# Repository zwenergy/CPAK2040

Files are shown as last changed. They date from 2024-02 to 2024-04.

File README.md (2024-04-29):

# CPAK2040
An RP2040-based controller pak for the N64.

## Overview
The main idea of CPAK2040 is to a have a simple, cheap and easily DIY-able controller pak alternative for the N64 which is non-volatile (meaning not relying on a battery to keep the controller pak data like the original based on SRAM). 
For this, a Raspberry Pi Pico board is used, as it is widely available, cheap and easy to solder even for beginners.

A regular Raspberry Pi Pico board has a 2 MB Flash, whereas a single N64 controller pak has a capacity of 32 kB.
The software running on the Pico to emulate the controller pak only takes up a fraction of the available Flash memory, hence quite many "virtual controller paks" can be stored in the Pico's Flash.
By default, the CPAK2040 holds 10 "virtual controller paks", as a more efficient navigating method needs to implemented to better use a larger number of controller paks.

**DO NOT CONNECT VIA USB WHEN PLUGGED IN A CONTROLLER!**

## BOM
Well, the BOM is short.
You need the **PCB** and a **Raspberry Pi Pico board**. 
**Don't use a Pi Pico W board**, use a regular one.

## PCB
The Gerber files to create the PCB can be found in the "gerber" folder.
You need to order the PCB with **1.2 mm thickness**, **ENIG or hard gold** and **bevelled edges** at the connector.
Using regular HASL is not recommended, as the PCB contacts quickly wear down, while solder may also rub onto the controller's connection pins.

## Setting up the Pi Pico
Hold down the BOOTSEL button, connect the Pi Pico via USB to your computer and drag'n'drop the .UF2 from the latest release onto the Pi Pico device.

## Using the CPAK2040
If you're using the CPAK2040 without the 3D printed case, make sure that you orientate the PCB correctly.
It's noted on the PCB, which side should face the front of the controller ("controller cable side") and which to the back of the controller ("Z-trigger side").

Initially, all virtual controller paks will be "corrupted", as they are not formatted as a controller pak data.
Start a game using a controller pak and hold START during the startup, this will bring up the controller pak manager.
Here, you can typically "repair" aka format the current virtual controller pak.

### Storing behaviour
The current controller pak's content is hold in the RP2040's SRAM.
When a write the controller pak happens, the updated contents are stored into the Flash.
In order to avoid unneccassary writes to the Flash, the Flash content is not directly updated, but a small timeout of some seconds is introduced, such that multiple writes can be combined into a single Flash rewrite.
This is signaled using the Pico's LED.
When then LED is on, this means that there is fresh data in the controller pak which is not written back to the Flash yet.
**Do not unplug the controller pak, while the LED is on, or otherwise you risk losing the latest controller pak data or data corruption.**

This delayed storing behaviour is done to reduce the number of Flash rewrites.
The Flash has a limited number of writes of ca. 100,000 before it wears out.
**This also means, that each "virtual controller pak" on the CPAK2040 has a lifetime of around 100,000 writes.**
Realistically, this should be enough forever for most people I guess.
If you save each day 10 times to the controller pak, you can do that for 27 years straight before you're getting close the 100,000 writes.

### Changing Virtual Controller Pak
To change the current virtual controller pak (VCP), shortly the BOOTSEL button down (<1 second).
The CPAK2040 will jump to the next VCP, indicating the current index by flashing the LED.
After the last VCP, the index will jump back to the first.
The current VCP index is stored into the Flash after 2s not changing it, so also after unplugging the CPAK2040 it will remember the last VCP used.

Note that many games will not reload the controller pak content, unless they sense that the controller pak is physically removed and plugged back in again.

The simple "hold button to increase VCP index" is not ideal, especially with a larger number of VCPs.
I am planning on adding a better navigating scheme.

### Backup Controller Pak Data
When plugging in the CPAK2040 via USB to a computer, the BOOTSEL button long (>2 seconds) and let go (**AFTER** plugging in via USB).
This enables USB read mode, which registers the CPAK2040 as a mass storage device and all the controller paks can be copied off the device (this is implemented using TinyUSB).
There is currently no way to manually exit the USB mode again, so the CPAK2040 needs to be unplugged before used again normally.

### Writing Controller Pak Data
This is currently still in **experimental mode**.

**ALWAYS MAKE A BACKUP OF YOUR SAVE GAMES!**

To enter USB write mode, hold the BOOTSEL button long (>2 seconds), let go shortly, then again hold it long (**AFTER** plugging in via USB).
This enables USB write mode, which registers the CPAK2040 as a mass storage device.
In this mode, only the current chosen VCP is visible and named "MEMPAK.MPK".
**IMPORTANT: Wait 5 seconds after mounting the USB drive before continuing.**
In order to replace this VCP, rename the memory pak file to be written to the CPAK2040 also to "MEMPAK.MPK" and copy it to the CPAK2040 drive (so it replaces the file on the drive).
After writing, the CPAK2040 should automatically disconnect and restart, showing the current chosen VCP via the blinking LED.

## Shell
A first version of a 3D printable shell can be found in the STL folder.

## Disclaimer
**Use the files and/or schematics to build your own board at your own risk**.
This board works fine for me, but it's a simple hobby project, so there is no liability for errors in the schematics and/or board files.
**Use at your own risk**.

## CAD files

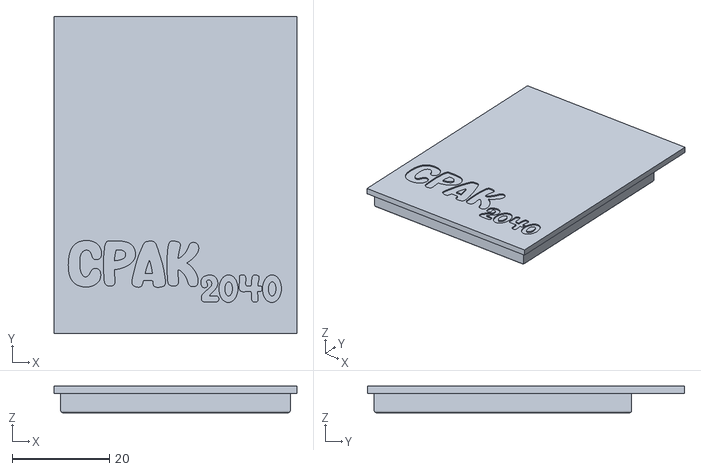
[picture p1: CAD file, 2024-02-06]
stl/front.stl
50.0 x 65.2 x 5.50

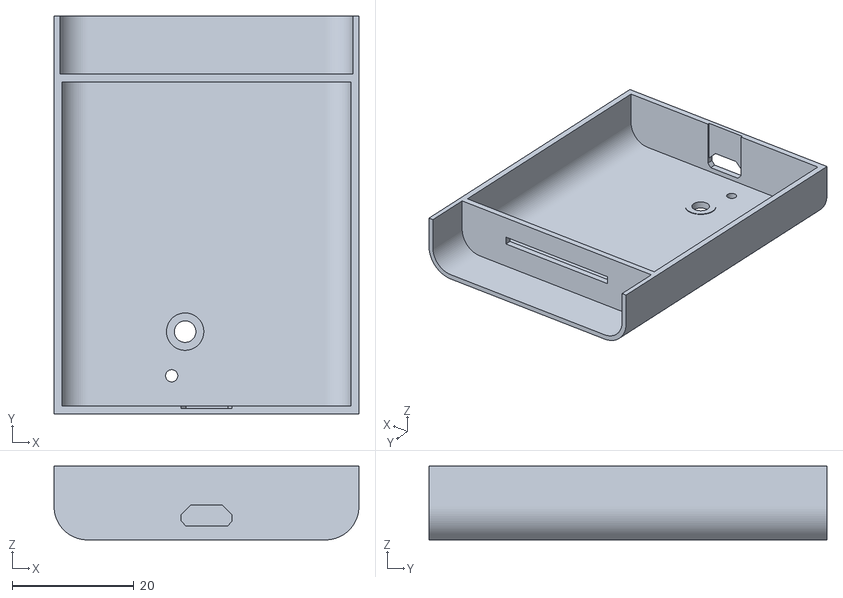
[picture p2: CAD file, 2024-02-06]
stl/back.stl
50.0 x 65.2 x 12.1

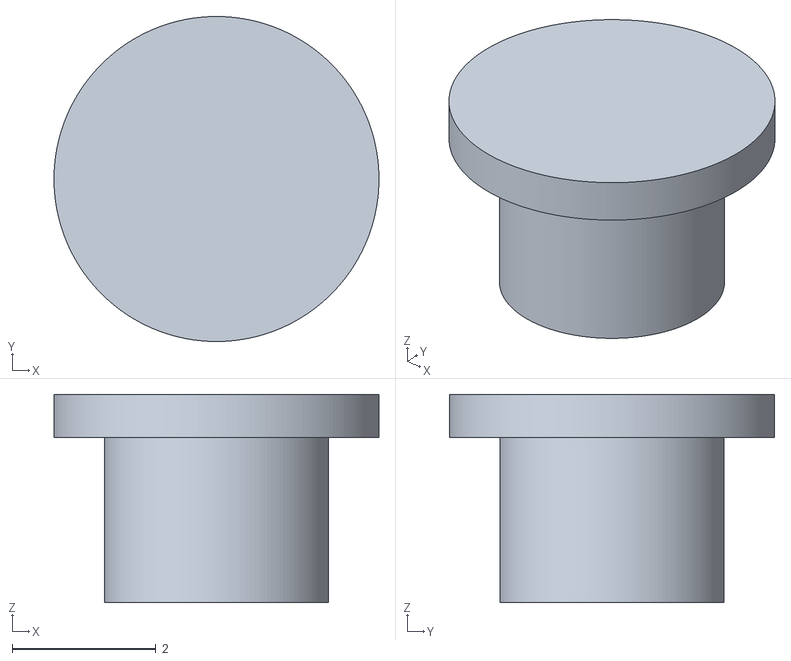
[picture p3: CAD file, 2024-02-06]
stl/button.stl
4.53 x 4.53 x 2.90

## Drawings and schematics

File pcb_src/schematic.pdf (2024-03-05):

A | A

1

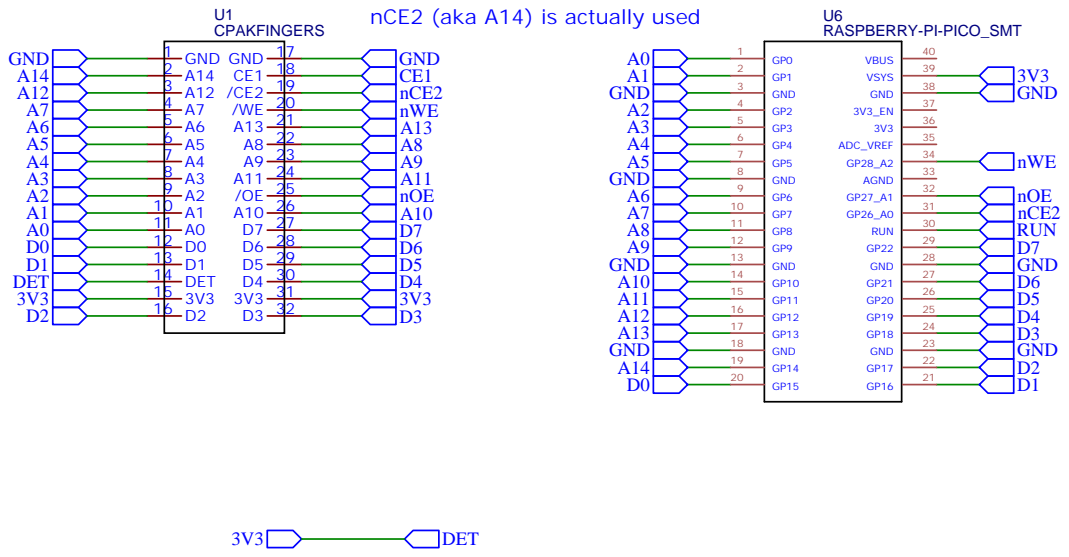
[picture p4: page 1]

nCE2 (aka A14) is actually used

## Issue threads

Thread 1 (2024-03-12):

Could vibration function be added?

natlus2, 2024-03-12:
the possibility of adding vibration, using the rumble of a mobile phone for example.

I don't know if it would be possible to run memory pak and rumble pak at the same time, if it were not possible, you could alternate between modes.

zwenergy, 2024-03-13:
It's difficult with the current simplicity of just using a single Pico, because there is not a single GPIO left to use to control a rumble motor. If I do a new version, which is not based on the Pico, but an own design around the RP2040, I could add this.

Closed 2024-03-13.

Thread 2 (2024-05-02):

Can not comiple !?

kirk33, 2024-05-02:
I try to compile, but it can not. I miss something ?

In file included from C:\PicoSDK\pico-sdk\lib\tinyusb\src/tusb.h:73,
                        from Z:\cpak\code\usb_descriptors.c:26:
C:\PicoSDK\pico-sdk\lib\tinyusb\src/device/usbd.h:247:58: error: 'MSC_SUBCLASS_SCSI' undeclared here (not in a function)

  247 |   9, TUSB_DESC_INTERFACE, _itfnum, 0, 2, TUSB_CLASS_MSC, MSC_SUBCLASS_SCSI, MSC_PROTOCOL_BOT, _stridx,\
      |                                                          ^~~~~~~~~~~~~~~~~
Z:\cpak\code\usb_descriptors.c:100:3: note: in expansion of macro 'TUD_MSC_DESCRIPTOR'
  100 |   TUD_MSC_DESCRIPTOR(ITF_NUM_MSC, 3 , EPNUM_MSC_OUT, EPNUM_MSC_IN, 64),
      |   ^~~~~~~~~~~~~~~~~~
C:\PicoSDK\pico-sdk\lib\tinyusb\src/device/usbd.h:247:77: error: 'MSC_PROTOCOL_BOT' undeclared here (not in a function);
 did you mean 'HID_PROTOCOL_BOOT'?
  247 |   9, TUSB_DESC_INTERFACE, _itfnum, 0, 2, TUSB_CLASS_MSC, MSC_SUBCLASS_SCSI, MSC_PROTOCOL_BOT, _stridx,\
      |                                                                             ^~~~~~~~~~~~~~~~
Z:\cpak\code\usb_descriptors.c:100:3: note: in expansion of macro 'TUD_MSC_DESCRIPTOR'
  100 |   TUD_MSC_DESCRIPTOR(ITF_NUM_MSC, 3 , EPNUM_MSC_OUT, EPNUM_MSC_IN, 64),

Closed 2024-05-03.

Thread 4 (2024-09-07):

[HELP] 30 mempacks

davidxgames, 2024-09-07:
"I couldn't increase it to more than 15 mempacks. Is it possible to do so, or would that be the limit? I would like to have about 30. Could you help me?"

zwenergy, 2024-09-08:
How exactly does your issue look like? For the USB functionality you'd need to adapt the FAT12 system, but the "pure" memory pack functionality should be working I think despite.

davidxgames, 2024-09-08:
> How exactly does your issue look like? For the USB functionality you'd need to adapt the FAT12 system, but the "pure" memory pack functionality should be working I think despite.

It works perfectly for me, except I want to add more mempacks but I can only do it up to 15:

`'M', 'E', 'M', 'P', 'A', 'K', '1', '5', 'M', 'P', 'K', 0x20, 0x00, 0xC6, 0x52, 0x6D,
                0x65, 0x43, 0x65, 0x43, 0x00, 0x00, 0x88, 0x6D, 0x65, 0x43, 0x42, 0x00,
                0x00, 0x80, 0x00, 0x00,

#define NRMEMPAKS 15`

But I can't add more, I even added a function so that if you quickly press the button twice it returns to the previous mempack.

I also added a second rp2040 to display the current mempack on a screen.

Could you tell me how to add more mempacks?

I don't speak English, I use Google Translate, so sorry.

zwenergy, 2024-09-09:
> `'M', 'E', 'M', 'P', 'A', 'K', '1', '5', 'M', 'P', 'K', 0x20, 0x00, 0xC6, 0x52, 0x6D,
0x65, 0x43, 0x65, 0x43, 0x00, 0x00, 0x88, 0x6D, 0x65, 0x43, 0x42, 0x00,
0x00, 0x80, 0x00, 0x00,

You also would have to adjust the FAT12 table, not just the root directory. Maybe also parts of the boot sector, I'm not sure about the sizes I put there right now. If you don't speak English, it would be probably the best if you would search for something like "FAT12 file system" in your native language to find an overview, how it is structured.

> edit: I understand, you're telling me that the 30 mempacks work on the console but I won't be able to see more than 15 when I connect to the PC?

Yes, I think if you only change the number of packs in main.c, it should still work on the console, but the regular USB storage view would be messed up.

davidxgames, 2024-09-11:
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

Hello, thanks for responding. I already tried modifying the FAT12 system, but I can't get it to work. I managed to compile with the 30 mempacks without errors, but when I connect it to the PC, it says the drive needs to be formatted. The thing is, I don't know how to program; the little I know, I've learned by modifying existing code. Hopefully, one day you'll have time to add more mempacks. With 30, I think it would be enough to have a definitive N64 controller pack.

I will send you a video via the social network X so you can see how I implemented the display to indicate the current mempack.

zwenergy, 2024-09-11:
Yeah, unfortunately it's not as simple as just adding more lines to the root directory part. The entries of the root directory part also point to the first sector of the file in the FAT table, so you would need to add sectors to the FAT and then set the right sector address in the newly added root directory entry.

Closed 2024-09-11.

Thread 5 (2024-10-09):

RumblePak only

davidxgames, 2024-10-09:
Hi, I saw that you commented on another issue (link: https://github.com/zwenergy/CPAK2040/issues/1) that adding rumble was possible, but not with the Pi Pico. Do you have any plans to emulate just the Rumble Pack using a Pi Pico?
Thank you in advance.

davidxgames, 2024-10-24:
I managed to emulate the rumble pak.

Closed 2024-10-24.

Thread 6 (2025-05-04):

extract the .uf2

FranTerrassa, 2025-05-04:
Hi, I've been trying to extract the .uf2 file for two hours, but I can't seem to do it. Could you please send me the compiled uf2 file?
Thanks and best regards.

zwenergy, 2025-05-05:
You can find the latest compiled .uf2 file here:
https://github.com/zwenergy/CPAK2040/releases/tag/v0.85

Also make sure that you use the correct FW according to the PCB/version you have (this one is not for the small RP2040-Zero, but for the larger Pi Pico).

FranTerrassa, 2025-05-05:
Sorry, I hadn't seen it.
Thanks and best regards

________________________________
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

Closed 2025-05-05.

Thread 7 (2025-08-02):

[feature request] Bank Switching for CPAK2040

mdluffy1234, 2025-08-02:
Recently, the YouTuber named Hunter R discovered that the N64 joybus protocol supports bank switching for higher capacity memory paks, and with a bodge wire and some slight modifications to the code, your PCB design also works with it.

Source: https://youtu.be/0cpjhIS6ClI?si=hVStMxrUg9sJwqBt

ra1ncode, 2025-08-02:
Been following this project (amongst many for a while) and this is super cool and would love to build one with it implemented.

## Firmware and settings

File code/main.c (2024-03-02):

#include "pico/stdlib.h"
#include "pico/multicore.h"
#include "hardware/flash.h"
#include "hardware/sync.h"
#include "hardware/structs/ioqspi.h"
#include "hardware/structs/sio.h"
#include "pico/time.h"
#include "hardware/watchdog.h"

// USB-related
#include "bsp/board.h"
#include "tusb_config.h"

// Pin Definitions.
#define A0 0
#define A1 1
#define A2 2
#define A3 3
#define A4 4
#define A5 5
#define A6 6
#define A7 7
#define A8 8
#define A9 9
#define A10 10
#define A11 11
#define A12 12
#define A13 13
#define A14 14
#define D0 15
#define D1 16
#define D2 17
#define D3 18
#define D4 19
#define D5 20
#define D6 21
#define D7 22
#define NCE 26
#define NOE 27
#define NWE 28

#define DATAOFFSET 15

#define LED_INT 25

#define FLASH_CS_PIN 1

// Bit masks
#define DATAMASK  0b00000011111111000000000000000
#define WRITEMASK 0b10000000000000000000000000000
#define CEMASK    0b00100000000000000000000000000
#define OEMASK    0b01000000000000000000000000000
#define CTRLMASK  0b11100000000000000000000000000

#define ADDRMASK  0b00000000000000111111111111111

#define MEMPAKSIZE 32768
#define NRMEMPAKS 10

// Address in the Flash for the first mem pak.
#define FLASHADDR ( PICO_FLASH_SIZE_BYTES - ( NRMEMPAKS * MEMPAKSIZE ) )

// Address in the Flash for the mempak counter.
#define MEMPAKCNTRADDR ( FLASHADDR - FLASH_SECTOR_SIZE )

// Idle time between checks of the listener.
#define REWRITECHECKINT_MS 500

// Waiting time after a write to the mem pak before the Flash is rewritten.
#define REWRITEWAIT_MS 5000

// Minimum time for a "long press"
#define LONGPRESS_MS 1500

// Maximum pause between button inputs for a sequence.
#define MAXPAUSE_MS 1000

// Maximum length of sequence.
#define MAXSEQUENCE 2

// Blink pattern interval.
#define BLINKPATTERNINT_MS 250

// Time for the current mempak index to be stored as the current one to
// Flash.
#define MEMPAKCHANGESTOREINDEX_MS 2000

// Time to restart after USB rewrite.
#define EJECTTIME_MS 500

// Some function declarations.
void writeMemPakToFlash( uint8_t* pak );
void readMemPakFromFlash( uint8_t pak[] );
void writeMemPakCntrToFlash();
uint8_t readMemPakCntrFromFlash();
void rewriteFlashListener();
void doMemPakAction();
uint32_t getBootSelButton();
void doBlinkPattern( uint32_t count );
void enterUSBMode();

extern uint32_t fullUSBWriteDone;

// The actual controller pak.
uint8_t mempak[ MEMPAKSIZE ];

// Flag variable to indicate re-write of the mem pak.
volatile uint32_t rewriteFlash = 0;

// Mempak counter
volatile uint8_t memPakCntr = 0;

// Which USB mode should be activated.
uint32_t usbReadMode = 1;

// An array for the last  button presses.
typedef enum pressType {
  LONGPRESS,
  SHORTPRESS
} pressType_t;

typedef enum actionHandle {
  NONE,
  NEXTPAK,
  USB_READ,
  USB_WRITE
} actionHandle_t;


void initGPIO() {
  // Set pin directions.
  gpio_init( A0 );
  gpio_set_dir( A0, GPIO_IN );
  gpio_init( A1 );
  gpio_set_dir( A1, GPIO_IN );
  gpio_init( A2 );
  gpio_set_dir( A2, GPIO_IN );
  gpio_init( A3 );
  gpio_set_dir( A3, GPIO_IN );
  gpio_init( A4 );
  gpio_set_dir( A4, GPIO_IN );
  gpio_init( A5 );
  gpio_set_dir( A5, GPIO_IN );
  gpio_init( A6 );
  gpio_set_dir( A6, GPIO_IN );
  gpio_init( A7 );
  gpio_set_dir( A7, GPIO_IN );
  gpio_init( A8 );
  gpio_set_dir( A8, GPIO_IN );
  gpio_init( A9 );
  gpio_set_dir( A9, GPIO_IN );
  gpio_init( A10 );
  gpio_set_dir( A10, GPIO_IN );
  gpio_init( A11 );
  gpio_set_dir( A11, GPIO_IN );
  gpio_init( A12 );
  gpio_set_dir( A12, GPIO_IN );
  gpio_init( A13 );
  gpio_set_dir( A13, GPIO_IN );
  gpio_init( A14 );
  gpio_set_dir( A14, GPIO_IN );
  
  gpio_init( NWE );
  gpio_set_dir( NWE, GPIO_IN );
  gpio_init( NCE );
  gpio_set_dir( NCE, GPIO_IN );
  gpio_init( NOE );
  gpio_set_dir( NOE, GPIO_IN );
  
  // Enable pull ups.
  gpio_set_pulls( NWE, true, false );
  gpio_set_pulls( NCE, true, false );
  gpio_set_pulls( NOE, true, false );
  
  // Initially, set the pins to IN
  gpio_init( D0 );
  gpio_set_dir( D0, GPIO_IN );
  gpio_init( D1 );
  gpio_set_dir( D1, GPIO_IN );
  gpio_init( D2 );
  gpio_set_dir( D2, GPIO_IN );
  gpio_init( D3 );
  gpio_set_dir( D3, GPIO_IN );
  gpio_init( D4 );
  gpio_set_dir( D4, GPIO_IN );
  gpio_init( D5 );
  gpio_set_dir( D5, GPIO_IN );
  gpio_init( D6 );
  gpio_set_dir( D6, GPIO_IN );
  gpio_init( D7 );
  gpio_set_dir( D7, GPIO_IN );
  
  gpio_init( LED_INT );
  gpio_set_dir( LED_INT, GPIO_OUT );
  
}

void softwareReset()
{
    watchdog_enable( 1, 1 );
    while( 1 );
}

// The actual live mem pak handling.
void __not_in_flash_func( doMemPakAction() ) {
  
  while ( 1 ) {
    unsigned int data = gpio_get_all();
    unsigned int ctrl = ( data & CTRLMASK );
    
    unsigned int curAddr = data & ADDRMASK;
        
    switch ( ctrl )
    {
      case 0x0:
      case 0x8000000:
        // Write.
        // (Behaviour of the SRAM chip used in the controller. If /WE is
        // low, write mode is enabled, ignoring the state of /OE).
        gpio_set_dir_in_masked( DATAMASK );
        uint8_t writeByte = ( data & DATAMASK ) >> DATAOFFSET;
        mempak[ curAddr ] = writeByte;
        
        // Set flag.
        rewriteFlash = 1;
        break;
      case 0x10000000:
        // Read.
        gpio_set_dir_out_masked( DATAMASK );
        uint8_t membyte = mempak[ curAddr ];
        unsigned int gpiobyte = membyte << DATAOFFSET;
        gpio_put_all( gpiobyte );
        break;
      default:
        gpio_set_dir_in_masked( DATAMASK );
    }
  }
  
}

int __not_in_flash_func( main() ) {
  set_sys_clock_khz(250000, true);
  
  initGPIO();
  
  // Read out mem pak counter.
  memPakCntr = readMemPakCntrFromFlash();
  
  // If never saved, this will return 0xFF
  if ( memPakCntr > NRMEMPAKS - 1 ) {
    memPakCntr = 0;
  }
  
  // Read out old mem pak from Flash.
  readMemPakFromFlash( mempak );
  
  // Start the actual mem pak handling on the second core.
  multicore_launch_core1( doMemPakAction );
  
  // Signal which mem pak is active.
  doBlinkPattern( memPakCntr + 1 );
  
  // Wait a bit to continue, so that the second core is up and running,
  // because the "checking bootsel button" function called in the 
  // rewriteFlashListener will temporarily disable Flash access.
  sleep_ms( 100 );

  // Start a listener to rewrite flash in case a
  // modification happens (never returns).
  rewriteFlashListener();

  return 0;
}


void __not_in_flash_func( writeMemPakToFlash( uint8_t* pak ) ) {
  // Not interrupt-safe.
  uint32_t ints = save_and_disable_interrupts();
  
  uint32_t curMemPakAddr = FLASHADDR + ( memPakCntr * MEMPAKSIZE );

  // Bytes to be erased have to be a multiple of the sector size.
  // A mem pak is 32768 bytes large.
  // A flash sector is 4096 bytes.
  // So it's naturally a multiple.
  flash_range_erase( curMemPakAddr, MEMPAKSIZE );

  // And write.
  // Bytes to be erased have to be a multiple of the page size.
  // A mem pak is 32768 bytes large.
  // A flash page size is 256 bytes.
  // So it's naturally a multiple.
  flash_range_program( curMemPakAddr, pak, MEMPAKSIZE );
  
  // Restore interrupts.
  restore_interrupts ( ints );
}

void readMemPakFromFlash( uint8_t pak[] ) {
  // Offset addr after the RAM (XIP_BASE).
  uint8_t* addr = (uint8_t*) ( XIP_BASE + FLASHADDR + ( memPakCntr * MEMPAKSIZE ) );
  
  // Go over byte-wise.
  // TODO: This is stupid, just read out 32b chunks.
  for ( int i = 0; i < MEMPAKSIZE; ++i ) {
    pak[ i ] = *addr;
    ++addr;
  }
}

void __not_in_flash_func( writeMemPakCntrToFlash() ) {
  // Dummy array, because we need to write in multiples of 
  // FLASH_PAGE_SIZE.
  uint8_t dummyArray[ FLASH_PAGE_SIZE ];
  dummyArray[ 0 ] = memPakCntr;
  
  // Not interrupt-safe.
  uint32_t ints = save_and_disable_interrupts();

  // Bytes to be erased have to be a multiple of the sector size.
  flash_range_erase( MEMPAKCNTRADDR, FLASH_SECTOR_SIZE );

  // And write.
  flash_range_program( MEMPAKCNTRADDR, dummyArray, FLASH_PAGE_SIZE );
  
  // Restore interrupts.
  restore_interrupts ( ints );
}

uint8_t __not_in_flash_func( readMemPakCntrFromFlash() ) {
  // Offset addr after RAM.
  uint8_t* addr = (uint8_t*) ( XIP_BASE + MEMPAKCNTRADDR );
  uint8_t cntr = *addr;
  
  return cntr;
}


// Keeps the timestamp in ms since the button is pressed, 0 if not pressed.
uint32_t pressedSince = 0;
// Keeps the timestamp in ms since the last button input.
uint32_t lastButtonRelease = 0;
pressType_t buttonSequence[ MAXSEQUENCE ];
uint32_t buttonSequenceInd = 0;

// Checks for button presses and handles them.
actionHandle_t __not_in_flash_func( buttonPressHandle() ) {
  // Check if active
  uint32_t btn = getBootSelButton();
  // Get time.
  uint32_t curTime = to_ms_since_boot( get_absolute_time() );
  
  if ( btn ) {
    // Newly pressed?
    if ( !pressedSince ) {
      pressedSince = curTime;
    }
    
  } else {
    // Check if it has been just released.
    if ( pressedSince ) {
      // Evaluate if long press or short press.
      pressType_t lastInput = SHORTPRESS;
      if ( curTime - pressedSince > LONGPRESS_MS ) {
        lastInput = LONGPRESS;
      }
      
      if ( buttonSequenceInd < MAXSEQUENCE ) {
        buttonSequence[ buttonSequenceInd ] = lastInput;
      }
      
      // Set back to zero.
      pressedSince = 0;
      lastButtonRelease = curTime;
      buttonSequenceInd++;
      
    } else {
      // Button is not pressed and also has not been released just now.
      // Check if a sequence is still ongoing.
      if ( lastButtonRelease ) {
        if ( curTime - lastButtonRelease >= MAXPAUSE_MS ) {
          
          // We just hit over the sequence timer.
          // Evaluate sequence.
          actionHandle_t retVal = NONE;
          if ( buttonSequenceInd == 1 ) {
            // One input.
            if ( buttonSequence[ 0 ] == SHORTPRESS ) {
              retVal = NEXTPAK;
            } else {
              retVal = USB_READ;
            }
            
          } else if ( buttonSequenceInd == 2 ) {
            // Two inputs.
            if ( buttonSequence[ 0 ] == LONGPRESS &&
                 buttonSequence[ 1 ] == LONGPRESS ) {
              retVal = USB_WRITE;
            }
          }
          
          // Set back to 0.
          lastButtonRelease = 0;
          buttonSequenceInd = 0;
          
          // Return value.
          return retVal;
        }
      }
    }
  }
  
  return NONE;
};

void __not_in_flash_func( rewriteFlashListener() ) {
  // This function basically just
  // waits for the Flash to be rewritten.
  // In order to avoid a lot of re-writes, we first wait a bit to make sure,
  // all mem pak writing is finished.
  
  // This function also listens to the bootsel button for changing the
  // virtual mem pak. We use the bootsel button, because we ran out of
  // regular GPIOs to use on a normal Pico board.
  
  uint32_t indexChange = 0;
  uint32_t indexChangeTime = 0;
  
  while ( 1 ) {
    // Check if we should rewrite.
    if ( rewriteFlash ) {
      
      while ( 1 ) {
        // Toggle the flag.
        rewriteFlash = 0;
        
        gpio_put( LED_INT, 1 );
        
        // Wait a bit.
        sleep_ms( REWRITEWAIT_MS );
        
        // Did no new write happen?
        if ( !rewriteFlash ) {
          writeMemPakToFlash( mempak );
          rewriteFlash = 0;
          
          gpio_put( LED_INT, 0 );
          break;
        }
      }
    }
    
    
    // Check for button press.
    actionHandle_t act = buttonPressHandle();
    
    if ( act == USB_READ ) {
      usbReadMode = 1;
      enterUSBMode();
      
    } else if ( act == USB_WRITE ) {
      usbReadMode = 0;
      enterUSBMode();
      
    } else if ( act == NEXTPAK ) {
      // Increase mem pak counter.
      if ( memPakCntr >= NRMEMPAKS - 1 ) {
        memPakCntr = 0;
      } else {
        ++memPakCntr;
      }
      
      // Reload mem pak.
      readMemPakFromFlash( mempak );

      doBlinkPattern( memPakCntr + 1 );
      
      indexChange = 1;
      indexChangeTime = to_ms_since_boot( get_absolute_time() );
    }

    if ( indexChange ) {
      uint32_t curTime = to_ms_since_boot( get_absolute_time() );
      
      if ( ( curTime - indexChangeTime ) >= MEMPAKCHANGESTOREINDEX_MS ) {
        writeMemPakCntrToFlash( memPakCntr );
        indexChange = 0;
      }
    }
  }
}

// Very funny function to get the state of the bootsel button.
// Needs to be in RAM.
uint32_t __not_in_flash_func( getBootSelButton() ) {
  // Not interrupt-safe.
  uint32_t ints = save_and_disable_interrupts();
  
  // High-Z to Flash CS
  hw_write_masked( &ioqspi_hw->io[ FLASH_CS_PIN ].ctrl,
    GPIO_OVERRIDE_LOW << IO_QSPI_GPIO_QSPI_SS_CTRL_OEOVER_LSB,
    IO_QSPI_GPIO_QSPI_SS_CTRL_OEOVER_BITS );
    
  // Sleep function is in Flash (which is not working now), so we just
  // count up a bit.
  for ( volatile int32_t i = 0; i < 3000; ++i );
  
  // Read out the button state.
  uint32_t b = !( sio_hw->gpio_hi_in & ( 1u << FLASH_CS_PIN ) );

  // Enable the CS pin again.
  hw_write_masked( &ioqspi_hw->io[ FLASH_CS_PIN ].ctrl,
    GPIO_OVERRIDE_NORMAL << IO_QSPI_GPIO_QSPI_SS_CTRL_OEOVER_LSB,
    IO_QSPI_GPIO_QSPI_SS_CTRL_OEOVER_BITS );
  
  // Restore interrupts.
  restore_interrupts ( ints );
  
  return b;
}

void doBlinkPattern( uint32_t count ) {
  for ( uint32_t i = 0; i < count; ++i ) {
    gpio_put( LED_INT, 1 );
    sleep_ms( BLINKPATTERNINT_MS );
    gpio_put( LED_INT, 0 );
    sleep_ms( BLINKPATTERNINT_MS );
  }
}

void enterUSBMode() {
  // Start USB-related tasks.
  board_init();
  tusb_init();
  
  while ( 1 ) {
    tud_task();
    
    // In case a full rewrite happened, we restart the RP2040 to get back
    if ( fullUSBWriteDone && 
         ( to_ms_since_boot( get_absolute_time() ) - fullUSBWriteDone > EJECTTIME_MS ) ) {
      softwareReset();
    }
  }
}

// USB-related callback functions.

void tud_mount_cb(void)
{
  
}

// Invoked when device is unmounted
void tud_umount_cb(void)
{
  
}

// Invoked when usb bus is suspended
// remote_wakeup_en : if host allow us  to perform remote wakeup
// Within 7ms, device must draw an average of current less than 2.5 mA from bus
void tud_suspend_cb(bool remote_wakeup_en)
{
  (void) remote_wakeup_en;
}

// Invoked when usb bus is resumed
void tud_resume_cb(void)
{
  
}

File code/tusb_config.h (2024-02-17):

/*
 * The MIT License (MIT)
 *
 * Copyright (c) 2019 Ha Thach (tinyusb.org)
 *
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
 */

#ifndef _TUSB_CONFIG_H_
#define _TUSB_CONFIG_H_

#ifdef __cplusplus
 extern "C" {
#endif

//--------------------------------------------------------------------
// COMMON CONFIGURATION
//--------------------------------------------------------------------

// defined by board.mk
#ifndef CFG_TUSB_MCU
  #error CFG_TUSB_MCU must be defined
#endif

// RHPort number used for device can be defined by board.mk, default to port 0
#ifndef BOARD_DEVICE_RHPORT_NUM
  #define BOARD_DEVICE_RHPORT_NUM     0
#endif

// RHPort max operational speed can defined by board.mk
// Default to Highspeed for MCU with internal HighSpeed PHY (can be port specific), otherwise FullSpeed
#ifndef BOARD_DEVICE_RHPORT_SPEED
  #if (CFG_TUSB_MCU == OPT_MCU_LPC18XX || CFG_TUSB_MCU == OPT_MCU_LPC43XX || CFG_TUSB_MCU == OPT_MCU_MIMXRT10XX || \
       CFG_TUSB_MCU == OPT_MCU_NUC505  || CFG_TUSB_MCU == OPT_MCU_CXD56 || CFG_TUSB_MCU == OPT_MCU_SAMX7X)
    #define BOARD_DEVICE_RHPORT_SPEED   OPT_MODE_HIGH_SPEED
  #else
    #define BOARD_DEVICE_RHPORT_SPEED   OPT_MODE_FULL_SPEED
  #endif
#endif

// Device mode with rhport and speed defined by board.mk
#if   BOARD_DEVICE_RHPORT_NUM == 0
  #define CFG_TUSB_RHPORT0_MODE     (OPT_MODE_DEVICE | BOARD_DEVICE_RHPORT_SPEED)
#elif BOARD_DEVICE_RHPORT_NUM == 1
  #define CFG_TUSB_RHPORT1_MODE     (OPT_MODE_DEVICE | BOARD_DEVICE_RHPORT_SPEED)
#else
  #error "Incorrect RHPort configuration"
#endif

#ifndef CFG_TUSB_OS
#define CFG_TUSB_OS               OPT_OS_NONE
#endif

// CFG_TUSB_DEBUG is defined by compiler in DEBUG build
// #define CFG_TUSB_DEBUG           0

/* USB DMA on some MCUs can only access a specific SRAM region with restriction on alignment.
 * Tinyusb use follows macros to declare transferring memory so that they can be put
 * into those specific section.
 * e.g
 * - CFG_TUSB_MEM SECTION : __attribute__ (( section(".usb_ram") ))
 * - CFG_TUSB_MEM_ALIGN   : __attribute__ ((aligned(4)))
 */
#ifndef CFG_TUSB_MEM_SECTION
#define CFG_TUSB_MEM_SECTION
#endif

#ifndef CFG_TUSB_MEM_ALIGN
#define CFG_TUSB_MEM_ALIGN          __attribute__ ((aligned(4)))
#endif

//--------------------------------------------------------------------
// DEVICE CONFIGURATION
//--------------------------------------------------------------------

#ifndef CFG_TUD_ENDPOINT0_SIZE
#define CFG_TUD_ENDPOINT0_SIZE    64
#endif

//------------- CLASS -------------//
#define CFG_TUD_HID               0
#define CFG_TUD_CDC               0
#define CFG_TUD_MSC               1
#define CFG_TUD_MIDI              0
#define CFG_TUD_VENDOR            0

// HID buffer size Should be sufficient to hold ID (if any) + Data
#define CFG_TUD_HID_EP_BUFSIZE    16
#define CFG_TUD_MSC_EP_BUFSIZE   512

#ifdef __cplusplus
 }
#endif

#endif /* _TUSB_CONFIG_H_ */

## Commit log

2024-02-02 Added initial code and PCB gerber files.
2024-02-06 Added shell STL files.
    [back.stl, button.stl, front.stl]
2024-02-18 Added x2 panelized gerbers.
2024-03-05 Added PCB sources.
